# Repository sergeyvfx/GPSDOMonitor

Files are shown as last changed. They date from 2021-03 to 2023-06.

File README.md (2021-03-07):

# GPSDO Monitor

A tiny module which is connecting to a databus of GPSDO modules with the goal
to visualize when the PLL is locked, GPS time is stabilized and things like
this. Pretty much minimized version of Lady Heather from John Miles, KE5FX
implemented in microcontroller.

## Licensing

All the work done and implemented for this project is licensed under the
terms of MIT license.

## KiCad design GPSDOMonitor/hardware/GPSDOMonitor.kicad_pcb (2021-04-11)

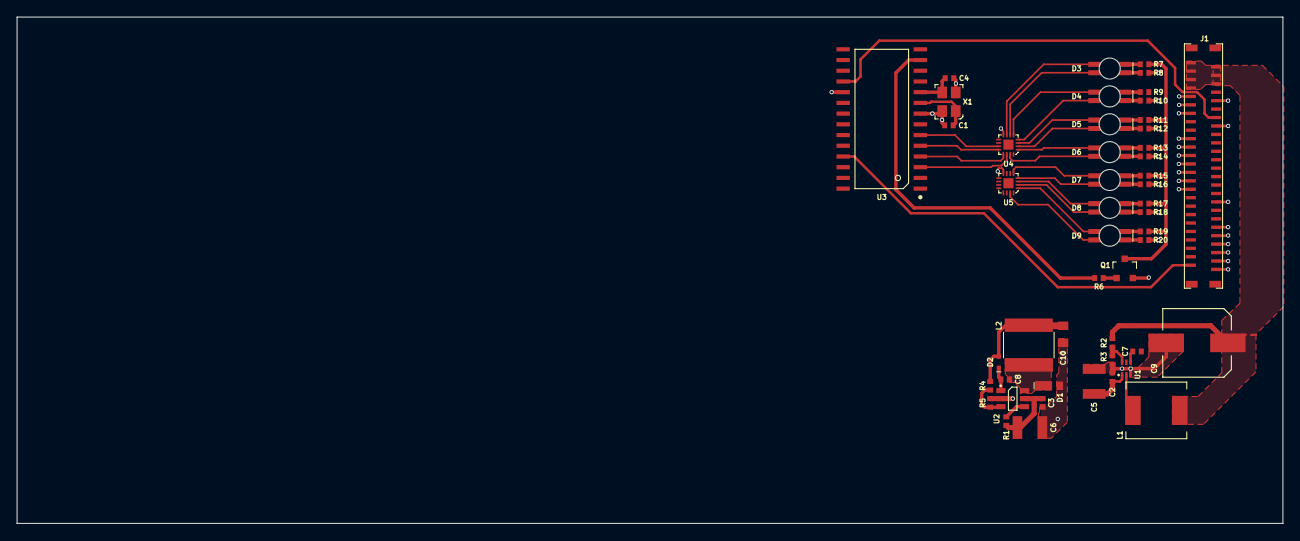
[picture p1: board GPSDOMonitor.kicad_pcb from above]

Board: 2 copper layers, 150.0 x 60.0 mm, 49 parts (0 on the bottom side), 51 nets.

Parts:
C1, C4: CBR04C409B5GAC; C_0402_1005Metric
C2, C3, C7, C8: UMK105B7104KV-FR; C_0402_1005Metric
C5, C6: UMK325AB7106KM-P; C_1210_3225Metric
C9: A768KE686M1GLAE038; CP_Elec_KEMET_8mm
C10: EMK212BB7106KG-T; C_0805_2012Metric
D1: SS14HE; SOD-323HE
D2: 1N914BWT; SOD-523
D3, D4, D5, D6, D7, D8, D9: 5977703607F
J1: F31S-1A7L1-11050
L1: ASPI-7318-4R7M-T; ASPI-7318
L2: NR6028T150M; NR6028
Q1: MMBT3904LT1G; SOT-23
R1: CRG0402ZR; R_0402_1005Metric
R2: CRGCQ0402F82K; R_0402_1005Metric
R3, R5: CRGCQ0402F10K; R_0402_1005Metric
R4: CRGCQ0402F33K; R_0402_1005Metric
R6: CRGCQ0402F1K0; R_0402_1005Metric
R7, R8, R9, R10, R11, R12, R13, R14, R15, R16, R17, R18, R19, R20: CRGCQ0402F68R; R_0402_1005Metric
U1: TPS563231DRLR; SOT-563
U2: MCP16301T-I_CHY; SOT-23-6
U3: PIC18LF2550-ISO; SOIC-28_Width7.50mm_Pitch1.27mm
U4, U5: SN74HC595BRWNR; X1QFN-16_EP_2.5x2.5mm
X1: ABM8W-20.0000MHZ-4-K1Z-T3; Crystal_SMD_4Pin_3.2x2.5mm

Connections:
+3V3: C10.1, D2.2, L2.2, R4.1, U3.20, U4.10, U5.10
+5V5: C9.1, J1.1, J1.2, J1.3, J1.4, J1.5, J1.6, J1.7, L1.2, R2.1
+12V: C2.1, C3.1, C5.1, C6.1, R1.1, U1.1, U1.5, U2.5
/LED_PWM: R6.2, U3.13
/OE: U3.4, U4.13, U5.13
/RCLK: U3.5, U4.12, U5.12
/SER: U3.3, U4.14
/SRCLK: U3.6, U4.11, U5.11
GND: C1.2, C2.2, C3.2, C4.2, C5.2, C6.2, C9.2, C10.2, D1.2, J1.9, J1.10, J1.11, J1.13, J1.16, J1.19, J1.21, J1.23, J1.25, J1.27, J1.29, J1.31, J1.34, J1.40, J1.42, J1.44, J1.46, J1.48, J1.50, Q1.2, R3.2, R5.2, R8.2, R10.2, R12.2, R14.2, R16.2, R18.2, R20.2, U1.3, U2.2, U3.8, U3.19, U4.8, U5.8, X1.2, X1.4
unnamed: C1.1, U3.9, X1.1
unnamed: C4.1, U3.10, X1.3
unnamed: C7.1, U1.4
unnamed: C7.2, L1.1, U1.2
unnamed: C8.1, D2.1, U2.1
unnamed: C8.2, D1.1, L2.1, U2.6
unnamed: D3.1, R8.1
unnamed: D3.2, U4.6
unnamed: D3.3, U4.7
unnamed: D3.4, R7.1
unnamed: D4.1, R10.1
unnamed: D4.2, U4.4
unnamed: D4.3, U4.5
unnamed: D4.4, R9.1
unnamed: D5.1, R12.1
unnamed: D5.2, U4.2
unnamed: D5.3, U4.3
unnamed: D5.4, R11.1
unnamed: D6.1, R14.1
unnamed: D6.2, U4.15
unnamed: D6.3, U4.1
unnamed: D6.4, R13.1
unnamed: D7.1, R16.1
unnamed: D7.2, U5.4
unnamed: D7.3, U5.5
unnamed: D7.4, R15.1
unnamed: D8.1, R18.1
unnamed: D8.2, U5.2
unnamed: D8.3, U5.3
unnamed: D8.4, R17.1
unnamed: D9.1, R20.1
unnamed: D9.2, U5.15
unnamed: D9.3, U5.1
unnamed: D9.4, R19.1
unnamed: Q1.1, R6.1
unnamed: Q1.3, R7.2, R9.2, R11.2, R13.2, R15.2, R17.2, R19.2
unnamed: R1.2, U2.4
unnamed: R2.2, R3.1, U1.6
unnamed: R4.2, R5.1, U2.3
unnamed: U4.9, U5.14
UART3_TxD: J1.14, U3.18
UART4_TX: J1.49, U3.25

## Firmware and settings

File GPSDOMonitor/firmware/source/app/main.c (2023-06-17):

// Copyright (c) 2021, Sergey Sharybin
//
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
// Author: Sergey Sharybin (sergey.vfx@gmail.com)

#include <stdbool.h>
#include <stdlib.h>
#include <xc.h>

#include "app/indication.h"
#include "base/check.h"
#include "gpsdo/gpsdo.h"
#include "system/system.h"
#include "system/task.h"
#include "time/time.h"
#include "uart/uart.h"

bool have_previous_gpsdo_status = false;
GPSDOStatus previous_gpsdo_status;

static bool HaveNewStatus(void) {
  const GPSDOStatus* gpsdo_status = GPSDO_GetStatus();

  bool have_new_status = true;
  if (have_previous_gpsdo_status) {
    have_new_status = !GPSDO_Status_Equal(&previous_gpsdo_status, gpsdo_status);
  }

  previous_gpsdo_status = *gpsdo_status;
  have_previous_gpsdo_status = true;

  return have_new_status;
}

static void reverse(char* str, int length) {
  int left = 0;
  int right = length - 1;
  while (left < right) {
    const char tmp = str[left];
    str[left] = str[right];
    str[right] = tmp;
    left++;
    right--;
  }
}

static char* UInt32ToString(uint32_t value, char* str, const size_t size) {
  int str_index = 0;

  if (value == 0) {
    // Simple case: value is 0. Do early output to simplify code dealing with
    // possible empty string output.
    DEBUG_CHECK(size >= 2);
    str[str_index++] = '0';
    str[str_index] = '\0';
    return str;
  }

  while (value != 0) {
    const uint8_t digit = value % 10;
    DEBUG_CHECK(str_index < size);
    str[str_index++] = digit + '0';
    value = value / 10;
  }

  DEBUG_CHECK(str_index < size);
  str[str_index] = '\0';

  reverse(str, str_index);

  DEBUG_CHECK(str[str_index] == '\0');

  return str;
}

static char* IntToString(int value, char* str, const size_t size) {
  int str_index = 0;

  if (value == 0) {
    // Simple case: value is 0. Do early output to simplify code dealing with
    // possible empty string output.
    DEBUG_CHECK(size >= 2);
    str[str_index++] = '0';
    str[str_index] = '\0';
    return str;
  }

  const bool is_negative = (value < 0);
  if (is_negative) {
    value = -value;
  }

  while (value != 0) {
    const uint8_t digit = value % 10;
    DEBUG_CHECK(str_index < size);
    str[str_index++] = digit + '0';
    value = value / 10;
  }

  if (is_negative) {
    DEBUG_CHECK(str_index < size);
    str[str_index++] = '-';
  }

  DEBUG_CHECK(str_index < size);
  str[str_index] = '\0';

  reverse(str, str_index);

  DEBUG_CHECK(str[str_index] == '\0');

  return str;
}

static void UpdateStatus(void) {
  if (!HaveNewStatus()) {
    return;
  }

  INDICATOR_Heartbeat();

  const GPSDOStatus* gpsdo_status = GPSDO_GetStatus();

  if (gpsdo_status->voltage_ok) {
    UART_WriteString("VCORE:OK  ");
    INDICATOR_PowerStatus(INDICATOR_STATUS_OK);
  } else {
    UART_WriteString("VCORE:FAIL");
    INDICATOR_PowerStatus(INDICATOR_STATUS_FAIL);
  }

  if (gpsdo_status->antenna_ok) {
    UART_WriteString(" ANT:OK  ");
    INDICATOR_AntennaStatus(INDICATOR_STATUS_OK);
  } else {
    UART_WriteString(" ANT:FAIL");
    INDICATOR_AntennaStatus(INDICATOR_STATUS_FAIL);
  }

  if (gpsdo_status->pll_status == GPSDO_PLL_UNLOCKED) {
    UART_WriteString(" PLL:UNLOCKED");
    INDICATOR_LockStatus(INDICATOR_STATUS_FAIL);
  } else if (gpsdo_status->pll_status == GPSDO_PLL_SYNCING) {
    UART_WriteString(" PLL:SYNCING ");
    INDICATOR_LockStatus(INDICATOR_STATUS_BLINKING);
  } else if (gpsdo_status->pll_status == GPSDO_PLL_LOCKED) {
    UART_WriteString(" PLL:LOCKED  ");
    INDICATOR_LockStatus(INDICATOR_STATUS_OK);
  } else {
    UART_WriteString(" PLL:UNKNOWN ");
    INDICATOR_LockStatus(INDICATOR_STATUS_FAIL);
  }

  if (gpsdo_status->leap_second_announced) {
    UART_WriteString(" LEAP_SECOND:YES");
  } else {
    UART_WriteString(" LEAP_SECOND:NO ");
  }

  if (gpsdo_status->have_gps_time) {
    UART_WriteString(" GPS_TIME_FLAG:OK  ");
  } else {
    UART_WriteString(" GPS_TIME_FLAG:FAIL");
  }

  {
    char gps_utc_offset_str[16];
    IntToString(gpsdo_status->gps_utc_offset,
                gps_utc_offset_str,
                sizeof(gps_utc_offset_str));
    UART_WriteString(" GPS-UTC:");
    UART_WriteString(gps_utc_offset_str);
  }

  {
    char gps_time_str[16];
    UInt32ToString(gpsdo_status->gps_time, gps_time_str, sizeof(gps_time_str));
    UART_WriteString(" GPS_TIME:");
    UART_WriteString(gps_time_str);
  }

  UART_WriteBuffer("\r\n", 2);
}

static void Tasks(void) {
  UpdateStatus();
}

static void APP_Initialize(void) {
  SYSTEM_Initialize();
  INDICATION_Initialize();
  GPSDO_Initialize();

  TASK_Register(&Tasks);

  // TODO(sergey): Run minimum amount of tasks needed to properly restore
  // configuration of the digital pot.

  // Make sure all transient states are stabilised. For example, that UART TX is
  // properly pulled up.
  //
  // TODO(sergey): When using PL2303HX-based Serial-to-USB dongle from eBay
  // there is a specific transition pattern on the TX pin of the
  // microcontroller: voltage first is pulled down from around 3v and then is
  // quickly raised up to 5v Vcc. This is where serial terminal will think there
  // is an incoming data. This delay mitigates the issue and the only outcome of
  // it is a first rubbish character in the terminal. Either need some sort of
  // external pull-up or a logic gate to avoid such high-low-hight transition on
  // the TX pin.
  DelayMilliseconds(10);

  UART_WriteString("\r\n");
  UART_WriteString("System initialisation finished.\r\n");
  UART_WriteString("\r\n");
  UART_WriteString("====================================\r\n");
  UART_WriteString("***         GPSDO Monitor        ***\r\n");
  UART_WriteString("====================================\r\n");
  // TODO(sergey): Print software and hardware versions.
  UART_WriteString("\r\n");
}

static void APP_StartUp(void) {
  // 1. Set the PWM period by writing to the PR2 register.
  //
  //   PR2 = PWM Period / (4 * Tosc * (TMR2 Prescale Value)) - 1
  //   PR2 = Fosc / (4 * Fpwm * (TMR2 Prescale Value)) - 1

  // From formula above calculated for 100KHz PWM frequency, Tosc based on 48MHz
  // Fosc, TMR2 prescale value of 4.
  PR2 = 29;

  // 2. Set the PWM duty cycle by writing to the CCPRxL register and
  //    CCPxCON<5:4> bits.
  //
  //   (CCPRxL:CCPxCON<5:4>) = PWM Duty Cycle / (Tosc * (TMR2 Prescale Value))
  //
  // NOTE: Duty cycle is measured in time, not in percentage.

  // From formula above calculated for 50%, Tosc based on 48MHz
  // Fosc, TMR2 prescale value of 4.
  const uint16_t ccp_duty_cycle = 60;

  CCP1CONbits.DC1B = ccp_duty_cycle & 0b00000011;
  CCPR1L = (ccp_duty_cycle >> 2) & 0xff;

  // 3. Set the TMR2 prescale value, then enable Timer2 by writing to T2CON.

  T2CONbits.TOUTPS = 0;  // No post-scaler.
  T2CONbits.T2CKPS = 1;  // Pre-scaler of 4.

  // 4. Configure the CCPx module for PWM operation.
  CCP1CONbits.CCP1M = 0b1100;

  // 5. Start the PWM.
  TMR2 = 0;
  T2CONbits.TMR2ON = 1;
}

void main(void) {
  APP_Initialize();
  APP_StartUp();

  for (;;) {
    TASK_Run();
  }
}

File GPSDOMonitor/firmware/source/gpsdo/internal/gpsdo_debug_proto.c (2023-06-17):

// Copyright (c) 2021, Sergey Sharybin
//
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
// Author: Sergey Sharybin (sergey.vfx@gmail.com)

#include "gpsdo/internal/gpsdo_debug_proto.h"

#include <xc.h>

#include "base/check.h"
#include "gpsdo/gpsdo.h"
#include "gpsdo/internal/gpsdo_parse.h"
#include "system/interrupt.h"
#include "system/task.h"
#include "uart/uart.h"

// Buffer size in bytes to store data received from the debug bus of the GPSDO.
//
// It is an intentionally bigger than the actual expected package size, so that
// in the case extra data is received it is possible to log enough data for an
// investigation.
#define DATA_BUFFER_SIZE 64

// Configure TMR3 to generate interrupt much less frequent than character will
// appear on GPSDO's debug UART.
//
// For the current chip selection it is 183.82 Hz (0.00544sec intervals).
//
// NOTE: Same timer is used to detect that data transmission is over.
#define TIMER3_VALUE 54656

// Machine states of the debug protocol receiver.
typedef enum MachineState {
  // Initial state.
  MAECHINE_STATE_INITIALIZE,

  // Skip current transmission from GPSDO to the uC.
  // Any received data in this state is ignored. The state is advanced when no
  // data is received for a while. This way starting uC in the middle of
  // transmission will not cause any issues
  MAECHINE_STATE_SKIP_PACKAGE,

  // There is no ongoing transmission, the machine need to initiate actual data
  // reception.
  MACHINE_STATE_BEGIN_RECEIVE_DATA,

  // Receive data from the GPSDO.
  MAECHINE_STATE_RECEIVE_DATA,

  // Package is fully received, and it needs to be copied over or parsed from
  // tasks routine.
  MAECHINE_STATE_PACKAGE_RECEIVED,

  // Error state when too much data from GPSDO is received.
  MAECHINE_STATE_ERROR_BUFFER_OVERFLOW,
  // Error state when new data was received while package was considered
  // finished and tasks were about to handle the data.
  MAECHINE_STATE_ERROR_BUFFER_COLLISION,
} MachineState;

// Context of the debug data receiver.
//
// It follows the debug UART (for example, UART3/Debug TxD) port and stores data
// transmitted from the module in this context for the further decoding.
typedef struct Context {
  MachineState machine_state;

  struct {
    int num_data_bytes;
    uint8_t data[DATA_BUFFER_SIZE];

    // Special flag which is used to detect end of data transmission.
    //
    // - It is set to false when state machine starts to expect a package.
    // - It is set to truth from data receive interrupt.
    // - It is checked from timer interrupt and if it is false it is considered
    //   an end of transmission (aka, no new data was received for long enough).
    bool received_data_in_time;
  } uart;

  struct GPSDOStatus* status;
} Context;

// TODO(sergey): Think of moving this to GPSDO state and not have it a global.
//
// The tricky part is that there is no heap allocation on 8 bit microcontrollers
// and in order to make it possible to stack-allocate this context a lot of a
// purely internal state is to exposed in the public header.
static Context g_context;

#define TIMER_RESET()                                                          \
  do {                                                                         \
    T3CONbits.TMR3ON = 0;                                                      \
    TMR3 = TIMER3_VALUE;                                                       \
    T3CONbits.TMR3ON = 1;                                                      \
  } while (false)

////////////////////////////////////////////////////////////////////////////////
// Interrupt handlers.

static void InterruptHandler(void) {
  // Receive interrupt.

  if (PIR1bits.RCIF && PIE1bits.RCIE) {
    // NOTE: Always read data to properly clear interrupt flags.
    const uint8_t data = RCREG;

    if (data) {
      asm("nop");
    }

    switch (g_context.machine_state) {
      case MAECHINE_STATE_INITIALIZE:
        // pass.
        break;

      case MAECHINE_STATE_SKIP_PACKAGE:
        // Skip current byte and reset timer, so that we keep ignoring the data
        // for until there is enough time elapsed without any data.
        TIMER_RESET();
        break;

      case MACHINE_STATE_BEGIN_RECEIVE_DATA:
        // pass.
        break;

      case MAECHINE_STATE_RECEIVE_DATA:
        if (g_context.uart.num_data_bytes >= DATA_BUFFER_SIZE) {
          g_context.machine_state = MAECHINE_STATE_ERROR_BUFFER_OVERFLOW;
          break;
        }

        // DEBUG_CHECK(g_context.uart.num_data_bytes < DATA_BUFFER_SIZE);
        g_context.uart.data[g_context.uart.num_data_bytes++] = data;

        g_context.uart.received_data_in_time = true;
        break;

      case MAECHINE_STATE_PACKAGE_RECEIVED:
        g_context.machine_state = MAECHINE_STATE_ERROR_BUFFER_COLLISION;
        break;

      case MAECHINE_STATE_ERROR_BUFFER_COLLISION:
      case MAECHINE_STATE_ERROR_BUFFER_OVERFLOW:
        // pass.
        break;
    }

    PIR1bits.RCIF = 0;  // Clear the interrupt flag.
  }

  // Timer3 interrupt.

  if (PIR2bits.TMR3IF && PIE2bits.TMR3IE) {
    switch (g_context.machine_state) {
      case MAECHINE_STATE_INITIALIZE:
        // pass.
        break;

      case MAECHINE_STATE_SKIP_PACKAGE:
        g_context.machine_state = MACHINE_STATE_BEGIN_RECEIVE_DATA;
        break;

      case MACHINE_STATE_BEGIN_RECEIVE_DATA:
        // pass.
        break;

      case MAECHINE_STATE_RECEIVE_DATA:
        if (!g_context.uart.received_data_in_time &&
            g_context.uart.num_data_bytes != 0) {
          // Has been long enough without any data received. Consider this as an
          // end of data transmission.
          g_context.machine_state = MAECHINE_STATE_PACKAGE_RECEIVED;
          break;
        }
        g_context.uart.received_data_in_time = false;
        break;

      case MAECHINE_STATE_PACKAGE_RECEIVED:
        // Do nothing, let the tasks handler to do their job (which could take
        // longer than the period of the timer).
        break;

      case MAECHINE_STATE_ERROR_BUFFER_COLLISION:
      case MAECHINE_STATE_ERROR_BUFFER_OVERFLOW:
        // pass.
        break;
    }

    PIR2bits.TMR3IF = 0;  // Clear the interrupt flag.
  }
}

////////////////////////////////////////////////////////////////////////////////
// Periodic tasks.
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

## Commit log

2021-03-06 Initial commit
    Implements timecode and debug protocol parser on PIC18F2550 and logs
    GPSDO status to the pic's UART.
    [configuration.h]
2021-03-07 Change directory layout
    Make it consistent with other electornics project.
    Allows to use own KiCAD library for the hardware part.
    [configuration.h]
2021-03-07 Add KiCAD library
2021-03-14 Initial commit of hardware part
    Puts KiCAD project in place, defines common part of microcontroller.
    [CPU.sch, GPSDOMonitor.kicad_pcb, GPSDOMonitor.sch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]
2021-03-20 Add connector for the GPSDO
    [CPU.sch, GPSDOMonitor.kicad_pcb]
2021-03-21 Add 5.5v regulator schematic
    [CPU.sch, GPSDOMonitor.kicad_pcb, GPSDOMonitor.sch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]
2021-03-21 Add 3.3v regulator for main CPU logic
    [GPSDOMonitor.kicad_pcb, GPSDOMonitor.sch]
2021-04-05 Fix comment in UART module
    [uart.c]
2021-04-05 Switch debug protocol to Timer3
    Frees up Timer2 to be used for PWM.
2021-04-05 Configure PWM
    Currently unused for anything other than debug purposes.
2021-04-05 Fix incorrect interrupt enable/flag check
    [gpsdo_timecode_proto.c]
2021-04-11 Add shift registers for indication
    [GPSDOMonitor.kicad_pcb, GPSDOMonitor.sch]
2021-04-11 Route power supplies
    [GPSDOMonitor.kicad_pcb, GPSDOMonitor.sch]
2021-04-11 Correct +5v5 fill zone
    [GPSDOMonitor.kicad_pcb]
2021-04-11 Route majority of the current board
    [GPSDOMonitor.kicad_pcb, GPSDOMonitor.sch]
2023-06-17 Ensure manipulation with FSR does not conflict
    Seems that changes in FSR register done from the interrupt
    handler function are not automatically restored, so do it
    explicitly.
    Solves memory corruption caused by UART print which seems to
    be using the same register.
2023-06-17 Make memory debugging easier
    - Pass buffer sized when known
    - Add macro which will cause panic on check failure
    Should be no functional changes.
    [gpsdo_debug_proto.c, main.c, system.c]
2023-06-17 Ensure transmission is finished before starting new one
    Possibly fixes transmitted string over the UART, which was
    sometimes corrupted.
    [uart.c]
2023-06-17 Changes to visualize status using 4 dual-color LEDs
    [configuration.h]
